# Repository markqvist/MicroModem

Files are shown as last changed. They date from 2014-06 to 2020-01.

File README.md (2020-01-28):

MicroModem - Deprecated Firmware
==========

*Please note that the firmware in this repo is deprecated! For a newer, much better general purpose firmware, use [MicroModemGP](https://github.com/markqvist/MicroModemGP). For an APRS-oriented firmware use [MicroAPRS](https://github.com/markqvist/MicroAPRS)*

*There is now a completely reworked hardware and software platform based on the legacy of MicroModem, called [OpenModem](https://github.com/markqvist/openmodem/), with many more features and a more flexible implementation.*

MicroModem is an educational implementation of a 1200-baud AFSK modem. This implementation is targeted at the Atmega 328p microprocessor used in many Arduino boards and spinoffs. It can be build very easily with an Arduino board based on the Atmega 328p, and around 15 common electronics components.

Please read the "Quickstart.pdf" in the Documentation folder for some pointers on building the modem!

If you want to use MicroModem for APRS, check out the [MicroAPRS](https://github.com/markqvist/MicroAPRS). This fork is created specifically for APRS.

MicroModem

The repository contains schematics and Eagle PCB files for a Microduino module. There is also fritzing sketches for both an Arduino shield and a Microduino module, with notes so they are easier to understand. I have had the eagle PCB fabricated, and it is working great, so you can use that if want to make your own board.

MicroModem

I am currently writing an illustrated tutorial to go along with the source-code, but even now, the source code is extremely well documented, and all the concepts are explained in great detail in the comments.

By default MicroModem uses a very simple protocol dubbed MP1. The protocol enables end-to-end transport with forward error-correction and compression. Compression is courtesy of the excellent [Heatshrink](https://github.com/atomicobject/heatshrink) library. MP1 can also encapsulate TCP/IP traffic from a host computer with SLIP.

MicroModem was created as an easy to build, low-cost and very flexible radio-modem. It also supports the AX.25 implementation in BertOS, so it can be used with that for APRS and the likes very easily.

While this project is based on Arduino hardware, it does not use the Arduino IDE. The project has been implemented in your normal C with makefile style, and uses libraries from the open source BertOS.

Visit [my site](http://unsigned.io) for questions, comments and other details.

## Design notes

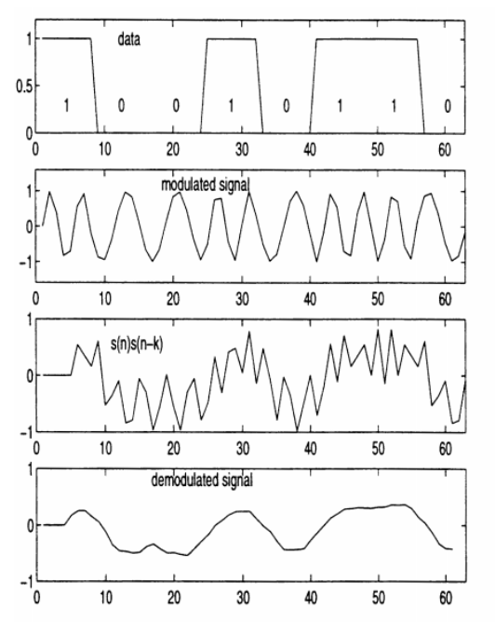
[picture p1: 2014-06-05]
Design/Images/fsk.png

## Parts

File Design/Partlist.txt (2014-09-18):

Partlist

Exported from Modem.sch at 9/18/14 8:45 PM

EAGLE Version 6.5.0 Copyright (c) 1988-2013 CadSoft

Assembly variant: 

Part           Value          Device         Package   Library        Sheet

C1             100nF          C2.5/2         C2.5-2    capacitor      1
C2             4.7uF          CPOL-EUE2.5-5V E2,5-4R   capacitor-pol  1
C3             1uF            C2.5/2         C2.5-2    capacitor      1
Q1             2N7000         2N7000         TO92      transistor     1
R1             1k             R-EU_0204/2V   0204V     resistor       1
R2             2k2            R-EU_0204/2V   0204V     resistor       1
R3             3k9            R-EU_0204/2V   0204V     resistor       1
R4             8k2            R-EU_0204/2V   0204V     resistor       1
R5             100k           R-EU_0204/2V   0204V     resistor       1
R6             1k             R-EU_0204/2V   0204V     resistor       1
R7             270            R-EU_0204/2V   0204V     resistor       1
R8             270            R-EU_0204/2V   0204V     resistor       1
R9             10k            R-EU_0204/2V   0204V     rcl            1
R10            100k           R-EU_0204/2V   0204V     rcl            1
R11            100k           R-EU_0204/2V   0204V     rcl            1
RX                            LED_ELD260     LED_LD260 eagle-ltspice  1
TX                            LED_ELD260     LED_LD260 eagle-ltspice  1

RADIO                         PINHD-1X3      1X03      adafruit       1
MICRODUINO_BTM                PINHD-1X9      1X09-BIG  adafruit       1
MICRODUINO_LFT                PINHD-1X9      1X09-BIG  adafruit       1
MICRODUINO_TOP                PINHD-1X9      1X09-BIG  adafruit       1
PTT+                          PINHD-1X1      1X01      adafruit       1
PTT-                          PINHD-1X1      1X01      adafruit       1

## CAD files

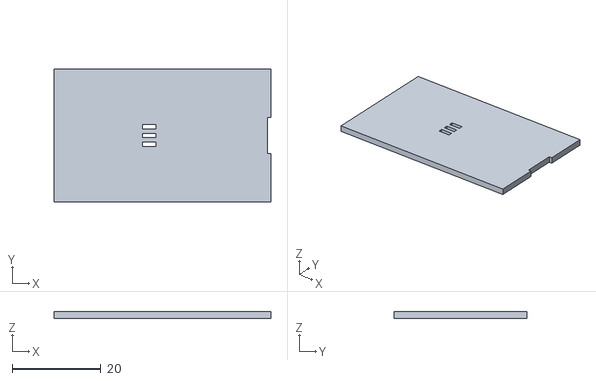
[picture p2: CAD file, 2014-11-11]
Design/Case/Enclosure_lid.stl
48.8 x 29.8 x 1.50

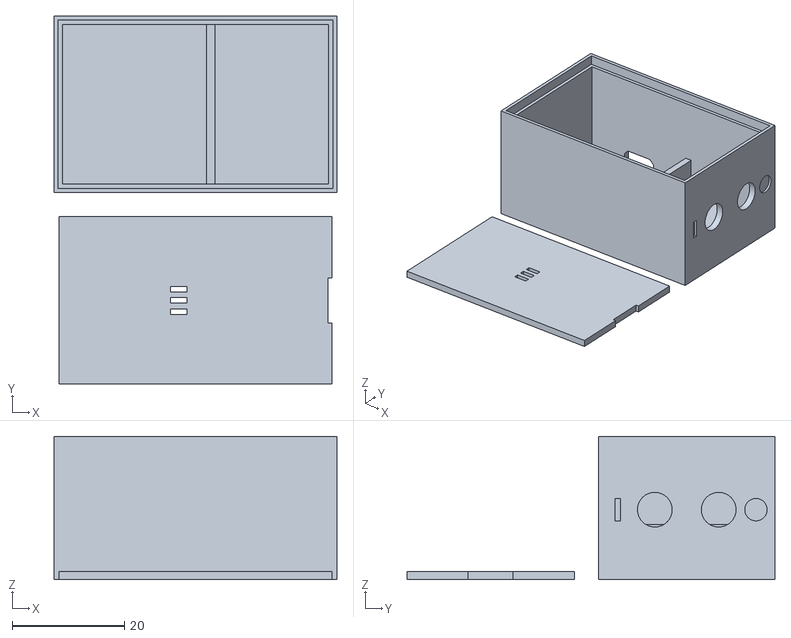
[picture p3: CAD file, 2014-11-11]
Design/Case/Modem_case.stl
50.5 x 65.7 x 25.6

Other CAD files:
Design/Case/Enclosure_rev0.scad

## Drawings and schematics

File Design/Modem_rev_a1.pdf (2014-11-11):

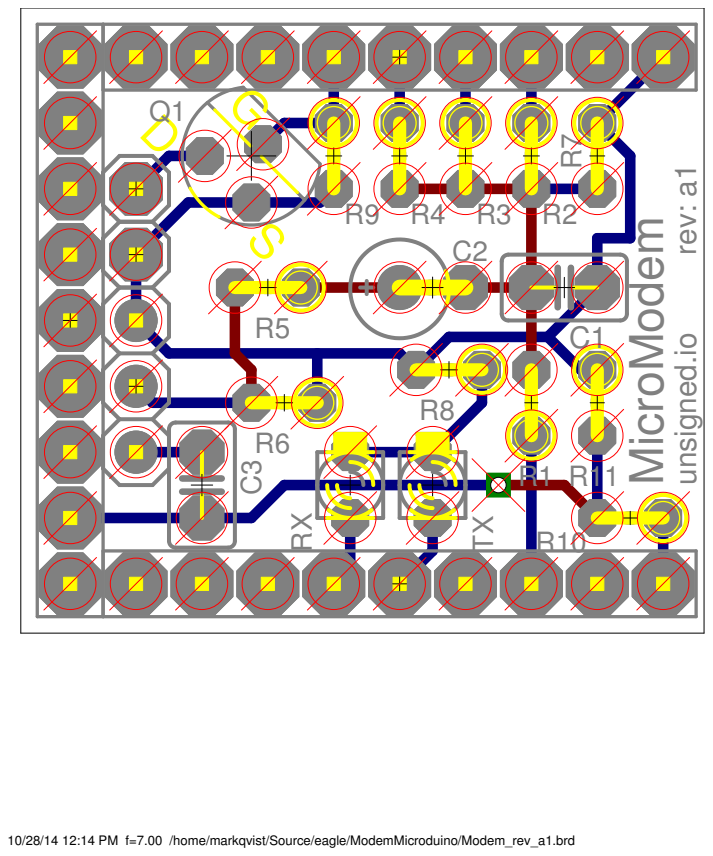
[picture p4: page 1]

10/28/14 12:14 PM f=7.00 /home/markqvist/Source/eagle/ModemMicroduino/Modem_rev_a1.brd

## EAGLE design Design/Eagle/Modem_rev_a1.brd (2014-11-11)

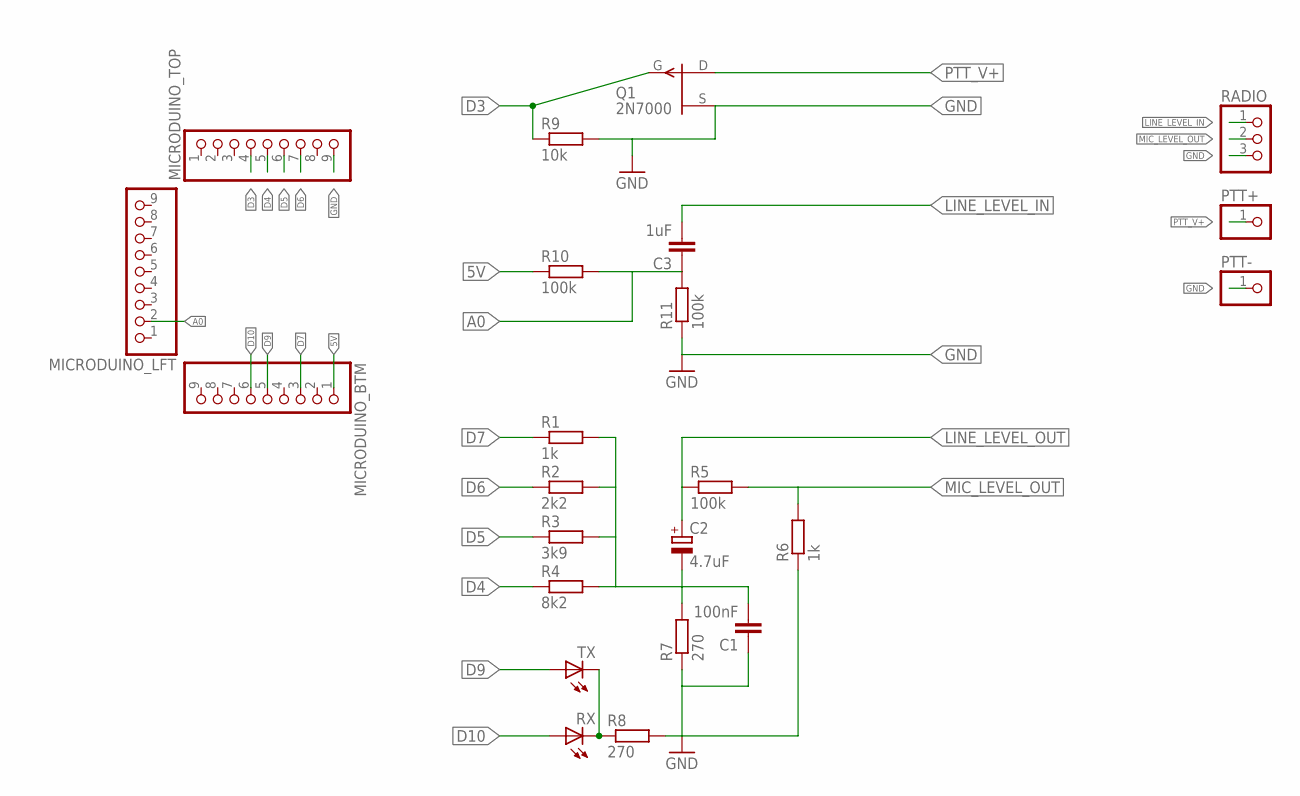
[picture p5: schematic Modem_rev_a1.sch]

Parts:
C1: 100nF; C2.5-2
C2: 4.7uF; E2,5-4R
C3: 1uF; C2.5-2
MICRODUINO_BTM: PINHD-1X9; 1X09-MICRODUINO
MICRODUINO_LFT: PINHD-1X9; 1X09-MICRODUINO
MICRODUINO_TOP: PINHD-1X9; 1X09-MICRODUINO
PTT+: PINHD-1X1; 1X01
PTT-: PINHD-1X1; 1X01
Q1: 2N7000; TO92_MOD
R1, R6: 1k; 0204V
R2: 2k2; 0204V
R3: 3k9; 0204V
R4: 8k2; 0204V
R5, R10, R11: 100k; 0204V
R7, R8: 270; 0204V
R9: 10k; 0204V
RADIO: PINHD-1X3; 1X03
RX: LED_ELD260; LED_LD260
TX: LED_ELD260; LED_LD260

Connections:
5V: MICRODUINO_BTM.1, R10.1
A0: C3.1, MICRODUINO_LFT.2, R10.2, R11.2
D3: MICRODUINO_TOP.4, Q1.2 (G), R9.1
D4: MICRODUINO_TOP.5, R4.1
D5: MICRODUINO_TOP.6, R3.1
D6: MICRODUINO_TOP.7, R2.1
D7: MICRODUINO_BTM.3, R1.1
D9: MICRODUINO_BTM.5, TX.A
D10: MICRODUINO_BTM.6, RX.A
GND: C1.1, MICRODUINO_TOP.9, PTT-.1, Q1.3 (D), R6.1, R7.1, R8.2, R9.2, R11.1, RADIO.3
LINE_LEVEL_IN: C3.2, RADIO.1
LINE_LEVEL_OUT: C2.+, R5.1
MIC_LEVEL_OUT: R5.2, R6.2, RADIO.2
unnamed: R8.1, RX.K (C), TX.K (C)
unnamed: C1.2, C2.-, R1.2, R2.2, R3.2, R4.2, R7.2
PTT_V+: PTT+.1, Q1.1 (S)

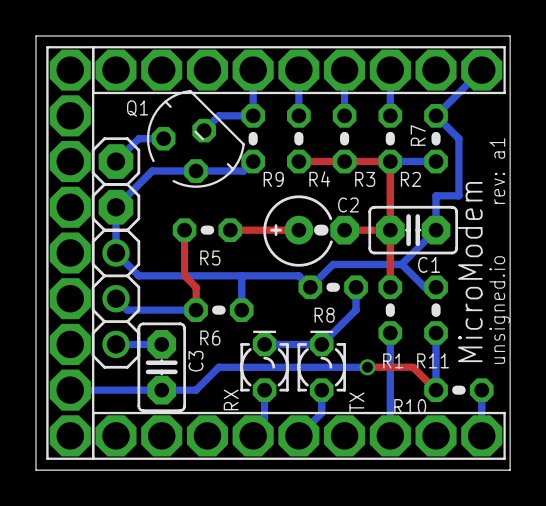
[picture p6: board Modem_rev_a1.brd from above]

Board: 2 copper layers, 26.3 x 24.1 mm, 23 parts (0 on the bottom side), 16 nets.

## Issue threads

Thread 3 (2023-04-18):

Gerbers for full board?

s3c, 2023-04-18:
Thanks for the work you've done on this project, it looks like a really clean solution for my next project. Would you be willing to release the gerbers for the board you no longer offer for sale on your site?

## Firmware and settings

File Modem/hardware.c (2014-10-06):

//////////////////////////////////////////////////////
// First things first, all the includes we need     //
//////////////////////////////////////////////////////

#include "hardware.h"		// We need the header for this code
#include "afsk.h"           // We also need to know about the AFSK modem

#include <cpu/irq.h>        // Interrupt functions from BertOS

#include <avr/io.h>         // AVR IO functions from BertOS
#include <avr/interrupt.h>  // AVR interrupt functions from BertOS

// A reference to our modem "object"
static Afsk *modem;

//////////////////////////////////////////////////////
// And now for the actual hardware functions        //
//////////////////////////////////////////////////////

// If your CPU clock is a little off, you can compensate
// with this
#define FREQUENCY_CORRECTION 0

// This function initializes the ADC and configures
// it the way we need.
void hw_afsk_adcInit(int ch, Afsk *_modem)
{
    // Store a reference to our modem "object"
    modem = _modem;

    // Also make sure that we are not trying to use
    // a pin that can't be used for analog input
    ASSERT(ch <= 5);

    // We need a timer to control how often our sampling functions
    // should run. To do this we will need to change some registers.
    // First we do some configuration on the Timer/Counter Control
    // Register 1, aka Timer1.
    //
    // The following bits are set:
    // CS10: ClockSource 10, sets no prescaler on the clock,
    // meaning it will run at the same speed as the CPU, ie 16MHz
    // WGM13 and WGM12 together enables "Timer Mode 12", which
    // is Clear Timer on Compare, compare set to TOP, and the
    // source for the TOP value is ICR1 (Input Capture Register1).
    // TOP means that we specify a maximum value for the timer, and
    // once that value is reached, an interrupt will be triggered.
    // The timer will then start from zero again. As just noted,
    // the place we specify this value is in the ICR1 register.
    TCCR1A = 0;                                    
    TCCR1B = BV(CS10) | BV(WGM13) | BV(WGM12);

    // We now set the ICR1 register to what count value we want to
    // reset (and thus trigger the interrupt) at.
    // Since the timer is running at 16MHz, the counter will be
    // incremented 16 million times each second, and we want the
    // interrupt to trigger 9600 times each second. The formula for
    // calculating the value of ICR1 (the TOP value) is:
    //    (CPUClock / Prescaler) / desired frequency - 1
    // So that's what well put in this register to set up our
    // 9.6KHz sampling rate. Note that we can also specify a clock
    // correction to this calculation. If you measure your processors
    // actual clock speed to 16.095MHz, define FREQUENCY_CORRECTION
    // as 9500, and the actual sampling (and this modulation and
    // demodulation) will be much closer to an actual 9600 Hz.
    // No crystals are perfect though, and will also drift with
    // temperature variations, but if you have a board with a
    // crystal that is way off frequency, this can help alot.
    ICR1 = (((CPU_FREQ+FREQUENCY_CORRECTION)) / 9600) - 1;

    // Set reference to AVCC (5V), select pin
    // Set the ADMUX register. The first part (BV(REFS0)) sets
    // the reference voltage to VCC (5V), and the next selects
    // the ADC channel (basically what pin we are capturing on)
    ADMUX = BV(REFS0) | ch;

    DDRC &= ~BV(ch);    // Set the selected channel (pin) to input
    PORTC &= ~BV(ch);   // Initialize the selected pin to LOW
    DIDR0 |= BV(ch);    // Disable the Digital Input Buffer on selected pin

    // Now a little more configuration to get the ADC working
    // the way we want
    ADCSRB =    BV(ADTS2) | // Setting these three on (1-1-1) sets the ADC to
                BV(ADTS1) | // "Timer1 capture event". That means we can declare
                BV(ADTS0);  // an ISR in the ADC Vector, that will then get called
                            // everytime the ADC has a sample ready, which will
                            // happen at the 9.6Khz sampling rate we set up earlier
                
    ADCSRA =    BV(ADEN) |  // ADC Enable - Yes, we need to turn it on :)
                BV(ADSC) |  // ADC Start Converting - Tell it to start doing conversions
                BV(ADATE)|  // Enable autotriggering - Enables the autotrigger on complete
                BV(ADIE) |  // ADC Interrupt enable - Enables an interrupt to be called
                BV(ADPS2);  // Enable prescaler flag 2 (1-0-0 = division by 16 = 1MHz)
                            // This sets the ADC to run at 1MHz. This is out of spec,
                            // Since it's normal operating range is only up to 200KHz.
                            // But don't worry, it's not dangerous! I promise it wont
                            // blow up :) There is a downside to running at this speed
                            // though, hence the "out of spec", which is that we get
                            // a much lower resolution on the output. In this case,
                            // it's not a problem though, since we don't need the full
                            // 10-bit resolution, so we'll take fast and less precise!
}
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

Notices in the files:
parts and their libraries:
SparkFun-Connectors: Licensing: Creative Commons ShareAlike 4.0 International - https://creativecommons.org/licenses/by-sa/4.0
